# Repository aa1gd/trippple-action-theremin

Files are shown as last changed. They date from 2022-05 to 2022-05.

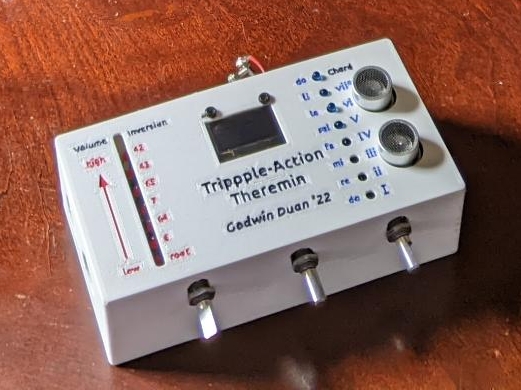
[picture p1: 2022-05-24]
images/inEnclosure.jpg

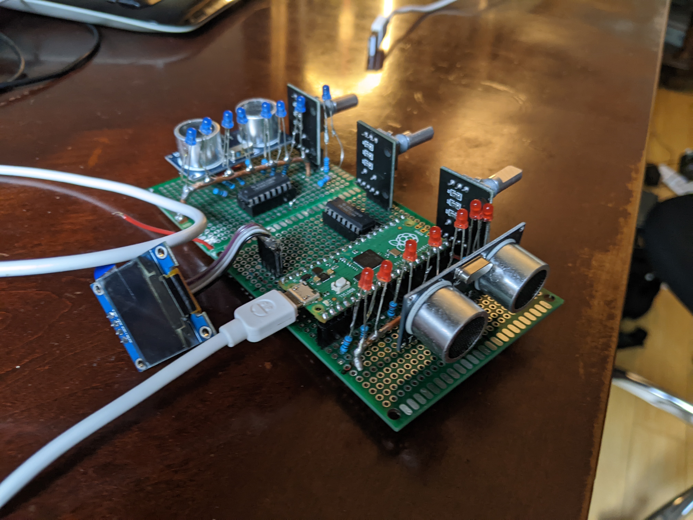
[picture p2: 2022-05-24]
images/circuitBoard.jpg

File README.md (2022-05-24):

What is this?
- A digital theremin that can play notes and chords following partwriting rules. It runs on a Raspberry Pi Pico, and uses tinyusb to function as a MIDI device. It was created for a final project in an AP Music Theory class.

Why is "triple" spelled incorrectly?
- It's not. Trippple has three p's. -Jacob

How to operate it?
Melody Mode:
- Right hand controls pitch. Left hand controls volume. Closer means quieter, farther away means louder.

Chords Mode:
- Right hand controls chord degree. Left hand controls chord inversion. When the desired chord has been selected (the LEDs will show you current selection), tap the foot pedal. The same exact chord cannot be played twice in a row.
- Screen will display the played chord's notes.

Figured Bass Mode:
- Like chords, but right hand controls the bass note. Left hand controls inversion.

Duet Mode:
- Both hands play notes at max volume; left hand is one octave lower than the right.

Knobs:
- Turn left knob to change key, press it to switch from major to minor
- Turn middle knob to change the operating mode. Press it to clear all currently playing notes (used if something went wrong)
- Turn right knob to change the MIDI channel. Can be used to switch synthesizer instruments.

What parts do I need?
- 1x Raspberry Pi Pico
- 2x HC-SR04 ultrasonic sensors
- 1x SSD1306 128x64 OLED display
- 2x SN74HC138N 3-8 decoder/demux ICs (used to control the LEDs)
- 3x Rotary encoders
- 15x LEDs + current limiting resistors
- 3D printer (for enclosure)
- A lot of patience

How do I compile it?
- It uses the Pico SDK. See https://datasheets.raspberrypi.com/pico/getting-started-with-pico.pdf

Known bugs:
- First chord played after startup can't be a root position i/I chord
- If the seventh of a seventh chord is suspended (remains on the same note), it will forget to go down.
- (Not a bug, but beware: all global variables must be static or else tinyusb will hate you. You may notice I went a bit overboard with adding "static" keywords to everything)
- Entire project was done in 6 days. The code is sloppy and inevitably has many more bugs I didn't find yet.

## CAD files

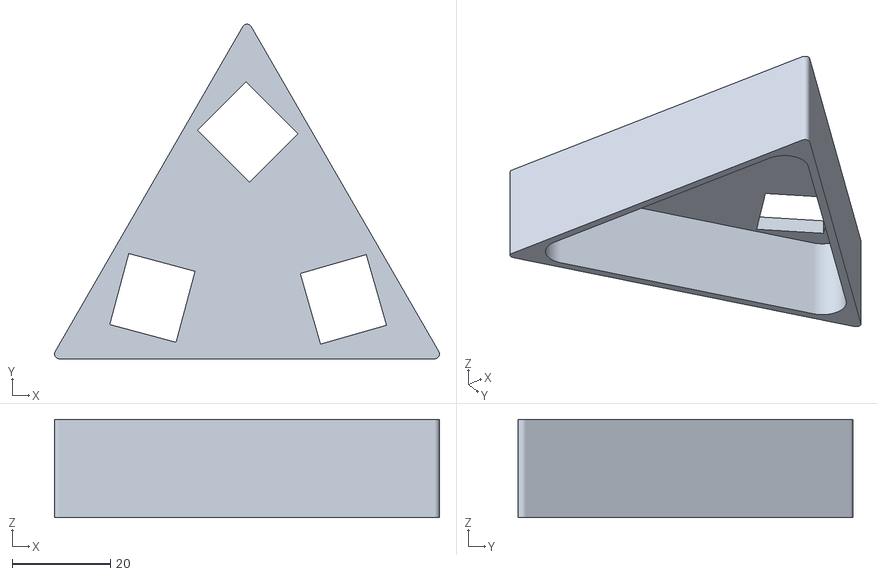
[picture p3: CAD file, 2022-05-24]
stls/footpedalbase.stl
78.5 x 68.3 x 20.0

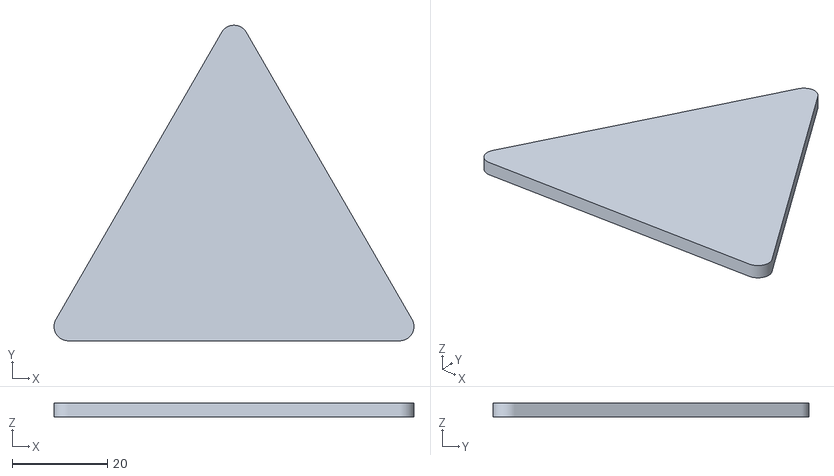
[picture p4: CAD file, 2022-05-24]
stls/footpedalplate.stl
75.6 x 66.3 x 3.00

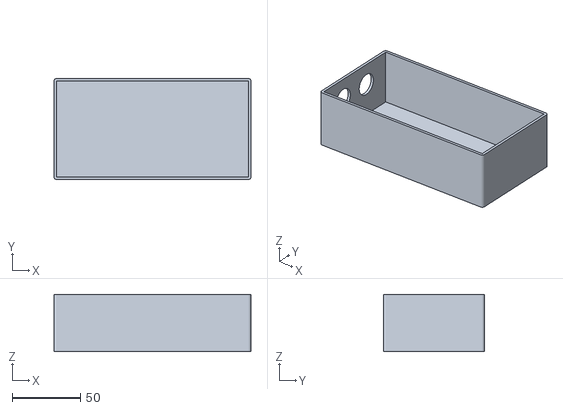
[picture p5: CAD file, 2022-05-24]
stls/casev1.stl
144.0 x 74.0 x 42.0

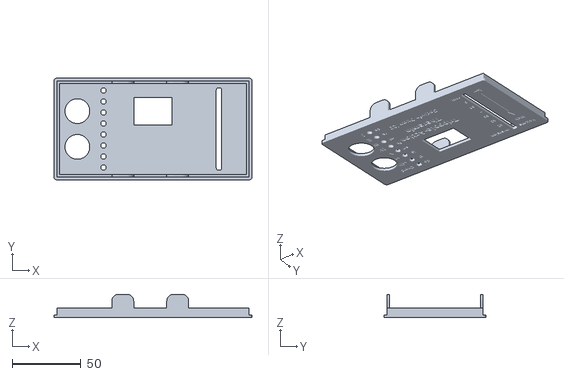
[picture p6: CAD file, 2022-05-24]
stls/lidv1.stl
144.0 x 74.0 x 17.0

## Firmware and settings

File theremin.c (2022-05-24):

/* Created by Godwin Duan May 17, 2022 - May 23, 2022 for Mr. Sato's 4th period AP Music Theory final project. */

#include <stdio.h>
#include <stdbool.h>
#include <string.h>
#include "pico/stdlib.h"
#include "hardware/gpio.h"
#include "pico/binary_info.h"

#include "bsp/board.h"
#include "tusb.h"

#include "chords.h"
#include "hc-sr04.h"
#include "ssd1306.h"

#define PITCH_OFFSET 0

#define DISPLAY_SDA_PIN 0
#define DISPLAY_SCL_PIN 1

#define ROTARY_1_CLK_PIN 13
#define ROTARY_1_DT_PIN 14
#define ROTARY_1_SW_PIN 15
#define ROTARY_2_CLK_PIN 5
#define ROTARY_2_DT_PIN 6
#define ROTARY_2_SW_PIN 7
#define ROTARY_3_CLK_PIN 2
#define ROTARY_3_DT_PIN 3
#define ROTARY_3_SW_PIN 4

#define SENSOR_1_TRIG_PIN 8
#define SENSOR_1_ECHO_PIN 9
#define SENSOR_2_TRIG_PIN 16
#define SENSOR_2_ECHO_PIN 17

#define MUX_1_A_PIN 18
#define MUX_1_B_PIN 19
#define MUX_1_C_PIN 20
#define MUX_2_A_PIN 10
#define MUX_2_B_PIN 11
#define MUX_2_C_PIN 12
#define MUX_2_DISABLE_PIN 21

#define FOOT_PEDAL_PIN 22

#define MAX_RANGE_1 64
#define MAX_RANGE_2 64

#define BLINK_NOT_MOUNTED 250
#define BLINK_MOUNTED 500
#define BLINK_SUSPENDED 1000

static volatile uint32_t blink_interval_ms = BLINK_NOT_MOUNTED;
static const uint LED_PIN = PICO_DEFAULT_LED_PIN;

void setup_gpios();
void led_blinking_task(void);
void midi_write_note(uint8_t note, uint8_t volume);
void midi_turn_off_note(uint8_t note);
void midi_reset_all();
void midi_play_chord(struct Chord previous, struct Chord next);

void tud_mount_cb(void);
void tud_umount_cb(void);
void tud_suspend_cb(bool remote_wakeup_en);
void tud_resume_cb(void);

void display_update(ssd1306_t *disp, char *line1, char *line2, char *line3, char *line4, char *line5);

void get_note_name(int pitch, char *name);

void setLeftMux(int light);
void setRightMux(int light);

void read_rotaries();
static bool prevStateCLK1;
static bool prevStateCLK2;
static bool prevStateCLK3;
static bool prevButtonState1;
static bool prevButtonState2;
static bool prevButtonState3;

// State variables for the 4 different operating modes
// Melody
static int prevMelodyNote = 0;
static int prevVolume = 0;

// Chords
// TODO: When I compiled, I had these two variables initialized as zero.
// Should have been something else as I chord cannot be played as the first chord
static int prevInversion = 0;
static int prevDegree = 0;
static volatile struct Chord second, third;

// Figured Bass
static int prevBassNote = 0;
static int prevFigBassInversion;

// Duet
static int prevDuetNote1 = 0;
static int prevDuetNote2 = 0;

static struct Note default_note; // is this even necessary?

static const int melodic_major_scale[8] = {0, 2, 4, 5, 7, 9, 11, 12};
static const int playable_natural_minor_scale[8] = {0, 2, 3, 5, 7, 8, 10, 12}; 

static const char note_names[12][3] = {"C", "C#", "D", "D#", "E", "F", "F#", "G", "G#", "A", "A#", "B"};
static const char alt_note_names[12][3] = {"", "Db", "", "Eb", "", "", "Gb", "", "Ab", "", "Bb", "B"};

static int key = 48;
static bool major = true;
static int operating_mode = 0; // 0 -> melodies, 1 -> chords, 2 -> figured bass, 3 -> melody harmonization
static int midi_channel = 0; // between 0 and 15

static ssd1306_t disp;

int main()
{
    // Neccesary?
    default_note.pitch = 0;
    default_note.isSeventh = false;
    default_note.isLeadingTone = false;

    third.notes[0] = default_note;
    third.notes[1] = default_note;
    third.notes[2] = default_note;
    third.notes[3] = default_note;
    third.score = -1;

    second = third;
    // end neccessary?

    setup_gpios();

    // for sensor diagnostics
    gpio_init(26);
    gpio_set_dir(26, GPIO_OUT);

    // Setup SSD1306 display
    disp.external_vcc = false;
    ssd1306_init(&disp, 128, 64, 0x3C, i2c0);
    ssd1306_clear(&disp);

    ssd1306_draw_string(&disp, 8, 24, 2, "Loading");
    ssd1306_show(&disp);

    // Get initial rotary readings
    prevStateCLK1 = gpio_get(ROTARY_1_CLK_PIN);
    prevStateCLK2 = gpio_get(ROTARY_2_CLK_PIN);
    prevStateCLK3 = gpio_get(ROTARY_3_CLK_PIN);

    prevButtonState1 = gpio_get(ROTARY_1_SW_PIN); // it's high when not pressed, low when pressed
    prevButtonState2 = gpio_get(ROTARY_2_SW_PIN);
    prevButtonState3 = gpio_get(ROTARY_3_SW_PIN);

    // initialize LEDs with a sweep
    for (int i = 0; i < 8; i++)
    {
        setLeftMux(i);
        setRightMux(i);
        busy_wait_ms(250);
    }
    // then turn them off
    setLeftMux(-1);
    setRightMux(-1);

    board_init();
    tusb_init();

    static bool twentysix = false;
    
    // Gives the computer some time to pick up the device
    absolute_time_t endstartup = delayed_by_ms(get_absolute_time(), 3000);
    while (absolute_time_diff_us(get_absolute_time(), endstartup) > 0)
        tud_task();

    ssd1306_clear(&disp);
    display_update(&disp, "", "", "", "", "");

    while (true)
        {
            gpio_put(26, twentysix);
            twentysix = !twentysix;

            led_blinking_task();

            uint8_t packet[4];
            while ( tud_midi_available() )
                tud_midi_packet_read(packet);

            // Check for rotary switch / button inputs
            read_rotaries();

            int vol, level, deg, pitch;

            if (operating_mode == 0) // single note melody mode
            {
                level = measure_median_interval(SENSOR_2_TRIG_PIN, SENSOR_2_ECHO_PIN, MAX_RANGE_2, 8);               
                vol = measure_median_interval(SENSOR_1_TRIG_PIN, SENSOR_1_ECHO_PIN, MAX_RANGE_1, 128);

                if (level == -1)
                {
                    if (prevMelodyNote != 0)
                        midi_turn_off_note(prevMelodyNote);
                    prevMelodyNote = 0;
                    continue;
                }

                if (vol == -1)
                    vol = 127;

                deg = level - PITCH_OFFSET;
                pitch = 0;

                if (deg >= 0)
                {
                    if (major)
                        pitch = melodic_major_scale[deg] + key;
                    else
                        pitch = playable_natural_minor_scale[deg] + key;
                } else
                {
                    deg += 7;
                    if (major)
                        pitch = melodic_major_scale[deg] + key - 12;
                    else
                        pitch = playable_natural_minor_scale[deg] + key - 12;
                }

                if (vol < 126)
                    setLeftMux(vol / 18);
                else
                    setLeftMux(6);
                setRightMux(deg);

                if (pitch != prevMelodyNote || vol != prevVolume)
                {
                    if (prevMelodyNote != 0)
                        midi_turn_off_note(prevMelodyNote);
                    midi_write_note(pitch, vol);
                    prevMelodyNote = pitch;
                    prevVolume = vol;
                }
            }
            else if (operating_mode == 1) // chords mode
            {
                int degree = measure_median_interval(SENSOR_2_TRIG_PIN, SENSOR_2_ECHO_PIN, MAX_RANGE_2, 7);               
                int inversionLevel = measure_median_interval(SENSOR_1_TRIG_PIN, SENSOR_1_ECHO_PIN, MAX_RANGE_1, 7);

                int inversion = inversionConversion(inversionLevel);

                // show LEDs with mux here
                setLeftMux(inversionLevel);
                setRightMux(degree);

                // active low foot pedal
                if ((degree != prevDegree || inversion != prevInversion) && !gpio_get(FOOT_PEDAL_PIN))
                {
                    genChord(key, major, degree + 1, inversion, second, &third);
                    midi_play_chord(second, third);
                    second = third;
                    prevDegree = degree;
                    prevInversion = inversion;
                    char line1[8] = "";
                    char line2[8] = "";
                    char line3[8] = "";
                    char line4[8] = "";
                    char line5[8] = "";

                    get_note_name(third.notes[3].pitch, line1);
                    get_note_name(third.notes[2].pitch, line2);
                    get_note_name(third.notes[1].pitch, line3);
                    get_note_name(third.notes[0].pitch, line4);

                    if (major)
                    {
                        switch (degree)
                        {
                        case 0:
                            sprintf(line5, "I");
                            break;

                        case 1:
                            sprintf(line5, "ii");
                            break;

                        case 2:
                            sprintf(line5, "iii");
                            break;

                        case 3:
                            sprintf(line5, "IV");
                            break;

                        case 4:
                            sprintf(line5, "V");
                            break;

                        case 5:
                            sprintf(line5, "vi");
                            break;

                        case 6:
                            sprintf(line5, "vii*");
                            break;
                        }
                    }
                    else
                    {
                        switch (degree)
                        {
                        case 0:
                            sprintf(line5, "i");
                            break;

                        case 1:
                            sprintf(line5, "ii*");
                            break;

                        case 2:
                            sprintf(line5, "III+");
                            break;

                        case 3:
                            sprintf(line5, "iv");
                            break;

                        case 4:
                            sprintf(line5, "V");
                            break;

                        case 5:
                            sprintf(line5, "VI");
                            break;

                        case 6:
                            sprintf(line5, "vii*");
                            break;
                        }
                    }

                    char wordInversion[3];
                    sprintf(wordInversion, "%2d", inversion);
                    if (inversion != 0)
                        strcat(line5, wordInversion);

                    display_update(&disp, line1, line2, line3, line4, line5);
                }
            }
            else if (operating_mode == 2) // figured bass mode
            {
                int bNote = measure_median_interval(SENSOR_2_TRIG_PIN, SENSOR_2_ECHO_PIN, MAX_RANGE_2, 7);               
                int invLevel = measure_median_interval(SENSOR_1_TRIG_PIN, SENSOR_1_ECHO_PIN, MAX_RANGE_1, 7);
                
                int inv = inversionConversion(invLevel);

                int actualNumeral = figBassToNumeral(key, major, bNote, inv);
                // Show mux leds here
                setLeftMux(invLevel);
                setRightMux(bNote);

                // Foot pedal active low
                if ((bNote != prevBassNote || inv != prevInversion) && !gpio_get(FOOT_PEDAL_PIN))
                {
                    genChord(key, major, actualNumeral + 1, inv, second, &third);
                    midi_play_chord(second, third);
                    second = third;
                    prevBassNote = bNote;
                    prevFigBassInversion = inv;

                    char line1[8] = "";
                    char line2[8] = "";
                    char line3[8] = "";
                    char line4[8] = "";
                    char line5[8] = "";

                    get_note_name(third.notes[3].pitch, line1);
                    get_note_name(third.notes[2].pitch, line2);
                    get_note_name(third.notes[1].pitch, line3);
                    get_note_name(third.notes[0].pitch, line4);

                    // TODO: add sharps when key is minor
                    switch (actualNumeral)
                    {
                    case 0:
                        break;

                    case 1:
                        sprintf(line5, "6");
                        break;

                    case 2:
                        sprintf(line5, "64");
                        break;

                    case 3:
                        sprintf(line5, "7");
                        break;

                    case 4:
                        sprintf(line5, "65");
                        break;

                    case 5:
                        sprintf(line5, "43");
                        break;

                    case 6:
                        sprintf(line5, "42");
                        break;
                    }
                    display_update(&disp, line1, line2, line3, line4, line5);
                }
            }
            else if (operating_mode == 3) // duet mode
            {
                // note1 is bass (an octave lower), note2 is soprano
                int note1 = measure_median_interval(SENSOR_1_TRIG_PIN, SENSOR_1_ECHO_PIN, MAX_RANGE_1, 8);               
                int note2 = measure_median_interval(SENSOR_2_TRIG_PIN, SENSOR_2_ECHO_PIN, MAX_RANGE_2, 8);

                // set lights
                if (note1 == 7)
                    setLeftMux(0);
                else 
                    setLeftMux(note1);
                
                setRightMux(note2);

                if (note1 == -1)
                {
                    if (prevDuetNote1 != 0)
                        midi_turn_off_note(prevDuetNote1);
                    prevDuetNote1 = 0;
                }

                if (note2 == -1)
                {
                    if (prevDuetNote2 != 0)
                        midi_turn_off_note(prevDuetNote2);
                    prevDuetNote2 = 0;
                }

                // no pitch offset here... one octave is enough
                if (major)
                {
                    if (note1 != -1)
                        note1 = melodic_major_scale[note1] + key - 12;
                    if (note2 != -1)
                        note2 = melodic_major_scale[note2] + key;
                }
                else
                {
                    if (note1 != -1)
                        note1 = playable_natural_minor_scale[note1] + key - 12;
                    if (note2 != -1)
                        note2 = playable_natural_minor_scale[note2] + key;
                }

                if (note1 != -1 && note1 != prevDuetNote1)
                {
                    if (prevDuetNote1 != 0)
                        midi_turn_off_note(prevDuetNote1);
                    midi_write_note(note1, 127);
                    prevDuetNote1 = note1;
                }

                if (note2 != -1 && note2 != prevDuetNote2)
                {
                    if (prevDuetNote2 != 0)
                        midi_turn_off_note(prevDuetNote2);
                    midi_write_note(note2, 127);
                    prevDuetNote2 = note2;
                }
           }

            tud_task(); // tinyusb device task
        }
    return 0;
}

//--------------------------------------------------------------------+
// Device callbacks
//--------------------------------------------------------------------+

// Invoked when device is mounted
void tud_mount_cb(void)
{
    blink_interval_ms = BLINK_MOUNTED;
}

// Invoked when device is unmounted
void tud_umount_cb(void)
{
    blink_interval_ms = BLINK_NOT_MOUNTED;
}

// Invoked when usb bus is suspended
// remote_wakeup_en : if host allow us  to perform remote wakeup
// Within 7ms, device must draw an average of current less than 2.5 mA from bus
void tud_suspend_cb(bool remote_wakeup_en)
{
    (void)remote_wakeup_en;
    blink_interval_ms = BLINK_SUSPENDED;
}

// Invoked when usb bus is resumed
void tud_resume_cb(void)
{
    blink_interval_ms = BLINK_MOUNTED;
}

void midi_write_note(uint8_t note, uint8_t volume)
{
    uint8_t const cable_num = 0;

    uint8_t note_on[3] = { 0x90 | midi_channel, note, volume};
    tud_midi_stream_write(cable_num, note_on, 3);

}

void midi_turn_off_note(uint8_t note)
{ 
    uint8_t const cable_num = 0;

    uint8_t note_off[3] = { 0x80 | midi_channel, note, 0};
    tud_midi_stream_write(cable_num, note_off, 3);
}

void midi_reset_all(){
    for (int i = 21; i < 128; i++)
    {
        midi_turn_off_note(i);
    }
}

void midi_play_chord(struct Chord previous, struct Chord next)
{
    for (int i = 0; i < 4; i++)
        {
            // if (previous.notes[i].pitch > 0 && previous.notes[i].pitch < 128)
            midi_turn_off_note(previous.notes[i].pitch);
        }

    for (int i = 0; i < 4; i++)
        {
            midi_write_note(next.notes[i].pitch, 127);
        }
}

//--------------------------------------------------------------------+
// BLINKING TASK
//--------------------------------------------------------------------+
void led_blinking_task(void)
{
    static uint32_t start_ms = 0;
    static bool led_state = false;

    // Blink every interval ms
    if (board_millis() - start_ms < blink_interval_ms)
        return; // not enough time
    start_ms += blink_interval_ms;

    board_led_write(led_state);
    led_state = 1 - led_state; // toggle
}

void display_update(ssd1306_t *disp, char *line1, char *line2, char *line3, char *line4, char *line5)
{
    ssd1306_clear(disp);

    if (operating_mode == 0)
    {
        ssd1306_draw_string(disp, 0, 0, 1, "Melody");
    }
    else if (operating_mode == 1)
    {
        ssd1306_draw_string(disp, 0, 0, 1, "Chords");
    }
    else if (operating_mode == 2)
    {
        ssd1306_draw_string(disp, 0, 0, 1, "Fig B");
    }
    else if (operating_mode == 3)
    {
        ssd1306_draw_string(disp, 0, 0, 1, "Duet");
    }


    char channelName[8] = "";
    sprintf(channelName, "CHAN %d", midi_channel);
    ssd1306_draw_string(disp, 72, 0, 1, channelName);

    ssd1306_draw_string(disp, 0, 8, 1, "Key");
    char keyName[8] = "";
    get_note_name(key, keyName);

    ssd1306_draw_string(disp, 30, 8, 1, keyName);

    if (major)
        ssd1306_draw_string(disp, 84, 8, 1, "Major");
    else
        ssd1306_draw_string(disp, 84, 8, 1, "Minor");
    
    if (strlen(line1) != 0)
    {
        if (strlen(line1) <= 3)
            ssd1306_draw_string(disp, 56, 17, 1, line1);
        else
            ssd1306_draw_string(disp, 36, 17, 1, line1);
    }
    if (strlen(line2) != 0)
    {
        if (strlen(line2) <= 3)
            ssd1306_draw_string(disp, 56, 26, 1, line2);
        else
            ssd1306_draw_string(disp, 36, 26, 1, line2);
    }
    if (strlen(line3) != 0)
    {
        if (strlen(line3) <= 3)
            ssd1306_draw_string(disp, 56, 35, 1, line3);
        else
            ssd1306_draw_string(disp, 36, 35, 1, line3);
    }
    if (strlen(line4) != 0)
    {
        if (strlen(line4) <= 3)
            ssd1306_draw_string(disp, 56, 44, 1, line4);
        else
            ssd1306_draw_string(disp, 36, 44, 1, line4);
    }
    if (strlen(line5) != 0)
    {
        if (strlen(line5) <= 3)
            ssd1306_draw_string(disp, 56, 53, 1, line5);
        else
            ssd1306_draw_string(disp, 36, 53, 1, line5);
    }
    ssd1306_show(disp);
}

void setup_gpios()
{
    setup_ssd_gpios();

    gpio_init(ROTARY_1_CLK_PIN);
    gpio_init(ROTARY_1_DT_PIN);
    gpio_init(ROTARY_1_SW_PIN);
    gpio_init(ROTARY_2_CLK_PIN);
    gpio_init(ROTARY_2_DT_PIN);
    gpio_init(ROTARY_2_SW_PIN);
    gpio_init(ROTARY_3_CLK_PIN);
    gpio_init(ROTARY_3_DT_PIN);
    gpio_init(ROTARY_3_SW_PIN);

    gpio_set_dir(ROTARY_1_CLK_PIN, GPIO_IN);
    gpio_set_dir(ROTARY_1_DT_PIN, GPIO_IN);
    gpio_set_dir(ROTARY_1_SW_PIN, GPIO_IN);
    gpio_set_dir(ROTARY_2_CLK_PIN, GPIO_IN);
    gpio_set_dir(ROTARY_2_DT_PIN, GPIO_IN);
    gpio_set_dir(ROTARY_2_SW_PIN, GPIO_IN);
    gpio_set_dir(ROTARY_3_CLK_PIN, GPIO_IN);
    gpio_set_dir(ROTARY_3_DT_PIN, GPIO_IN);
    gpio_set_dir(ROTARY_3_SW_PIN, GPIO_IN);

    init_sonar();

    gpio_init(MUX_1_A_PIN);
    gpio_init(MUX_1_B_PIN);
    gpio_init(MUX_1_C_PIN);
    gpio_init(MUX_2_A_PIN);
    gpio_init(MUX_2_B_PIN);
    gpio_init(MUX_2_C_PIN);
    gpio_init(MUX_2_DISABLE_PIN);

    gpio_set_dir(MUX_1_A_PIN, GPIO_OUT);
    gpio_set_dir(MUX_1_B_PIN, GPIO_OUT);
    gpio_set_dir(MUX_1_C_PIN, GPIO_OUT);
    gpio_set_dir(MUX_2_A_PIN, GPIO_OUT);
    gpio_set_dir(MUX_2_B_PIN, GPIO_OUT);
    gpio_set_dir(MUX_2_C_PIN, GPIO_OUT);
    gpio_set_dir(MUX_2_DISABLE_PIN, GPIO_OUT);

    gpio_init(FOOT_PEDAL_PIN);
    gpio_set_dir(FOOT_PEDAL_PIN, GPIO_IN);
    gpio_pull_up(FOOT_PEDAL_PIN);
}
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

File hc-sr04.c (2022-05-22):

#include <stdlib.h>
#include "pico/stdlib.h"
#include <stdio.h>
#include "hardware/gpio.h"
#include "pico/time.h"
#include "pico/types.h"

#include "hc-sr04.h"

// for testing
#include "ssd1306.h"

#define SENSOR_1_TRIG_PIN 8
#define SENSOR_1_ECHO_PIN 9
#define SENSOR_2_TRIG_PIN 16
#define SENSOR_2_ECHO_PIN 17

#define MEDIAN_NUM_SAMPLES 5

// used for qsort
// TODO this loses precision on floats because it's casting to int...
static int cmpfunc (const void * a, const void * b) {
   return ( *(int*)a - *(int*)b );
}

void init_sonar()
{
    // setup the trigger pin in putput mode and echo pin to input mode
    gpio_init(SENSOR_1_TRIG_PIN);
    gpio_init(SENSOR_1_ECHO_PIN);
    gpio_set_dir(SENSOR_1_TRIG_PIN, GPIO_OUT);
    gpio_set_dir(SENSOR_1_ECHO_PIN, GPIO_IN);
    
    gpio_init(SENSOR_2_TRIG_PIN);
    gpio_init(SENSOR_2_ECHO_PIN);
    gpio_set_dir(SENSOR_2_TRIG_PIN, GPIO_OUT);
    gpio_set_dir(SENSOR_2_ECHO_PIN, GPIO_IN);
}

float measure_distance(int trigger_pin, int echo_pin, int max_range){
    float distance_cm = 0.0;

    // diagnostics
    //gpio_put(26, 0);

    gpio_set_input_enabled(echo_pin, 1 );
    gpio_put(trigger_pin, 0 ); // make sure that the pin is low
    busy_wait_ms(1);                // wait a bit to let things stabalize
    uint echo_result = gpio_get(echo_pin);
	// printf("\nPulsed the pin high echo pin is %d", echo_pin );
	
    gpio_put(trigger_pin, 1);  // go high
    busy_wait_ms(3);             // No need for 10 ms... only 10 us needed
    gpio_put(trigger_pin, 0);  // Switch the trigger low again to let the SR04 send the pulse
    
	/*
		The echo pin outputs a pulse between 150 micro-seconds and 25 mili-seconds, or if no object is found, it will send a 38 ms pulse. 
		speed of sound is 343 meters per second. This would depend upon the elevation and hummidity, but 
		sufficiently accurate for our application. 

		speed = distance travelled / time taken
		
		so, distance = (speed * time taken)/2 -- Divide by 2 because we are listening to the echo
		
		Now, speed of sound is 343 meters/second, whch is 3.43 centimeters per second, which is
		3.43/ 1000000 = 0.0343 cm/microsecond. 
		
		
	*/
    absolute_time_t  listen_start_time = get_absolute_time();
    //absolute_time_t  max_wait_time  = delayed_by_ms(listen_start_time, (int)(max_range * 2 / 34.3) + 5);  // No point waiting more than necessary.
	
    absolute_time_t  max_wait_time  = delayed_by_ms(listen_start_time, 19);  // No point waiting more than necessary. 38/2 = 19 should be enough (maybe?)

    while (true)
    {
        absolute_time_t  t_now = get_absolute_time();
        //if( t_now._private_us_since_boot > max_wait_time._private_us_since_boot )
        if (absolute_time_diff_us(max_wait_time, t_now) > 0)
        {
            //distance_cm = -69.0;
            break;
        }

        echo_result = gpio_get(echo_pin);
        if (echo_result != 0 ){   // We got an echo!
            //diagnostics
            //gpio_put(26, 1);

            absolute_time_t  first_echo_time = t_now;
            while (echo_result == 1 && absolute_time_diff_us(max_wait_time, t_now) < 0){
                echo_result = gpio_get(echo_pin );
                t_now = get_absolute_time();
            }
			if( echo_result == 1 ){
				break;	// will return 0 cm.
			}
            int64_t pulse_high_time = absolute_time_diff_us( first_echo_time, t_now );
			float pulse_high_time_float = (float) pulse_high_time;
            distance_cm = pulse_high_time_float * 0.01715; //pulse_high_time_float / 58.0 ;
            break;
        }
    }
    gpio_set_input_enabled(echo_pin, 0 );
    return distance_cm;
}

float measure_median_distance(int trigger_pin, int echo_pin, int max_range)
{
    float distances[MEDIAN_NUM_SAMPLES];

    for (int i = 0; i < MEDIAN_NUM_SAMPLES; i++)
    {
        distances[i] = measure_distance(trigger_pin, echo_pin, max_range);
    }

    qsort(distances, MEDIAN_NUM_SAMPLES, sizeof(float), cmpfunc);
    return distances[MEDIAN_NUM_SAMPLES / 2];
}

int make_interval(float distance, int divisions, int max_range)
{
    if (distance == 0.0)
        return -1;

    float gap_dist = (float)max_range / divisions;

    float interval = distance / gap_dist;

    // int interval = (int)distance; // make sure MAX_RANGE is a multiple of divisions
    //printf("gap dist %d and typecasted dist %d\n", gap_dist, interval);

    // interval /= gap_dist;

    //printf("now interval %d\n", interval);

    // low sol to high do is 11 divisions (sol, la, ti, do, re, mi, fa, sol, la, ti, do)
    // inversions are 7 (0, 6, 64, 7, 65, 43, 42)

    if (interval == divisions)
        return divisions - 1; // sensor is finnicky at the end so extend the last segment by one gap

    if (interval > divisions)
        return -1;

    return (int)interval;
}

int measure_median_interval(int trigger_pin, int echo_pin, int max_range, int divisions)
{
    int sorted_intervals[MEDIAN_NUM_SAMPLES];

    for (int i = 0; i < MEDIAN_NUM_SAMPLES; i++)
    {
        sorted_intervals[i] = make_interval(measure_distance(trigger_pin, echo_pin, max_range), divisions, max_range);
    }

    qsort(sorted_intervals, MEDIAN_NUM_SAMPLES, sizeof(float), cmpfunc);
    return sorted_intervals[MEDIAN_NUM_SAMPLES / 2];
}

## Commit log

2022-05-22 stuff is not working
    [hc-sr04.c, theremin.c]
2022-05-24 final code uploaded to board
2022-05-24 added STLs
    [casev1.stl, footpedalbase.stl, footpedalplate.stl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]
